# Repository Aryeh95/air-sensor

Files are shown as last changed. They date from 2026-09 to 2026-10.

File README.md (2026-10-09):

# Smart E-Ink Air Quality Monitor
This repository contains the ESPHome software configurations and 3D printed parts to build the Desktop Air Quality Monitor featured on [the channel](https://www.youtube.com/@FeatureNAB). 

> **This fork** builds the full variant **without a custom PCB**: it uses the off-the-shelf [Seeed Studio XIAO ePaper Display Board EE05](https://wiki.seeedstudio.com/epaper_ee05/) (XIAO ESP32-S3 Plus + e-paper driver) and a **Good Display GDEY0426T82** 4.26" 800x480 e-paper panel instead of the custom driver PCB and the 2.13" panel.

Watch the video (https://www.youtube.com/watch?v=DqiMmY5ppnE)

The device uses an ESP32 and the Sensirion SEN66 to track 9 different air quality metrics (PM1, PM2.5, PM4, PM10, VOCs, NOx, CO2, Temperature, and Humidity), plus formaldehyde with an optional Sensirion SFA40, and displays them on an e-ink screen. It connects natively to [Home Assistant](https://www.home-assistant.io/) and the firmware is written using [ESPHome](https://esphome.io/).

The original (2.13" + custom PCB) 3D files can be found on [Printables](https://www.printables.com/model/1751003-smart-desktop-air-quality-monitor-esp32-sen66), on [Makerworld](https://makerworld.com/en/models/2918992-smart-desktop-air-quality-monitor-esp32-sen66), or in the releases tab.
  
## What's in this Repository?

**If you just want the final ready-to-go files, check the [Releases tab](../../releases) on the right!**

All source files are organized into their respective folders: 

*   📂 **`enclosure/ee05_sen66_pod/`** - A SEN66 side-pod that bolts onto an EE05 + 4.26" enclosure, and the script that generates it.
*   📂 **`firmware/`** - ESPHome `.yaml` configuration files, plus precompiled bin files that you can flash directly to your board (Minimal and Home Assistant versions available).

## Getting Started

This project comes in 2 flavours - the minimal "just get the sensor working" variant, and the full variant with an e-paper display and a 3D printed housing.

### Minimal variant 

#### 1. Hardware
To build this version, you will need:

*   [Sensirion SEN66](https://mou.sr/44c63Ji)
*   [Seeed XIAO ESP32-C6](https://www.youtube.com/redirect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) microcontroller
*   [A JST-GH to Dupont cable](https://www.tinytronics.nl/en/cables-and-connectors/cables-and-adapters/jst-compatible/jst-ghr-06v-s-to-dupont-female-compatible-cable-6p-15cm) to connect them

Assemble by connecting the 3V, GND, SDA and SCL pins as shown in the video.

#### 2. Firmware

**Method A: "As Fast As Possible" (No Coding Required)**
1. If you plan to use the device with Home Assistant, download `Firmware_minimal_with_Home_Assistant_bins.zip `, if you plan to use it standalone use `Firmware_minimal_air_sensor_bins.zip ` from the Releases tab on the right side of this page.
2. Plug your ESP32 (C3, C5, C6, or S3) into your computer via USB.
3. Using a Web Serial compatible browser (like Chrome or Edge), go to [web.esphome.io](https://web.esphome.io).
4. Click "Connect", select your board's COM port, and upload the `.bin` file that matches your specific ESP32 model.
5. Connect to the device's fallback Wi-Fi network to add it to your home network!

**Method B: Do this if you already have Home Assistant (or want to customise your setup)**
1. Open the `Software` folder and grab the relevant `.yaml` config file. Copy its contents.
2. Paste it into your ESPHome Builder dashboard.
3. Edit your Wi-Fi credentials, encryption keys, and anything else you want to try.
4. "Install" to compile and flash directly to your board.

---

### Full Variant (EE05 + 4.26" e-paper, no custom PCB)

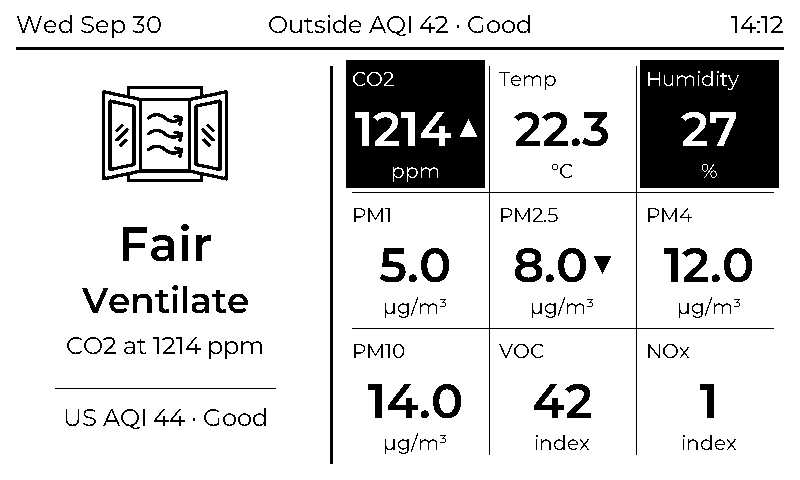
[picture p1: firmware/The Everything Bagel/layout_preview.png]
Display layout preview

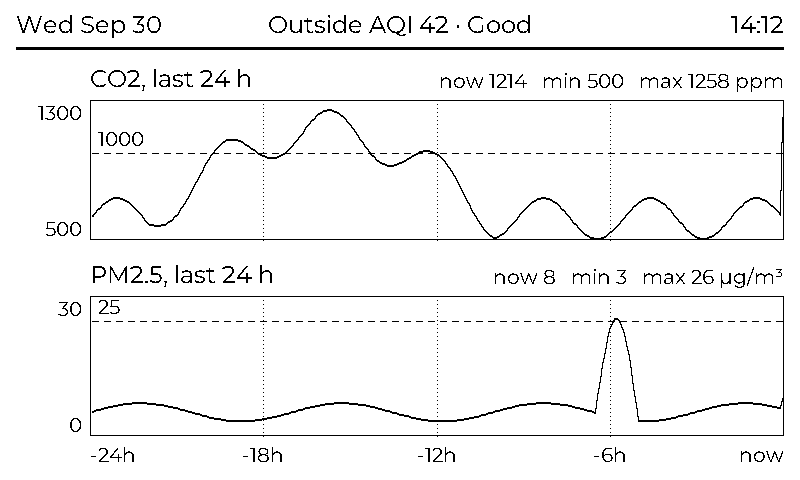
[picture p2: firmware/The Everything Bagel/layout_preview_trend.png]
Trend page preview

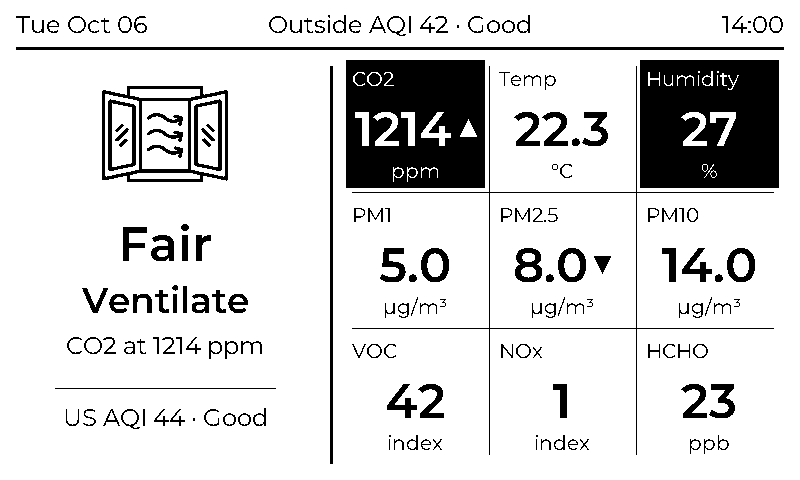
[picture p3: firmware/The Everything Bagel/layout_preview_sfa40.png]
With the optional SFA40 formaldehyde sensor


#### 1. Parts

| Part | Notes |
| --- | --- |
| [Sensirion SEN66](https://sensirion.com/products/catalog/SEN66) | The air quality sensor |
| JST GH 1.25 mm 6-pin cable, single-ended (plug on one end, bare wires on the other), 10–15 cm | SEN66 to EE05. Some SEN66 sellers include one |
| [Seeed Studio XIAO ePaper Display Board EE05](https://wiki.seeedstudio.com/epaper_ee05/) | XIAO ESP32-S3 Plus and 24-pin e-paper driver on one board. Replaces the custom PCB **and** the separate XIAO |
| [Good Display GDEY0426T82](https://buyepaper.com/products/gdey0426t82) | 4.26" 800x480 black/white e-paper (SSD1677), 24-pin FPC. Plugs straight into the EE05 |
| USB-C cable + 5 V supply | The SEN66's fan runs continuously, so run it from USB rather than a battery |
| EE05 + 4.26" enclosure (e.g. the "Cattt Casing") + the [SEN66 side-pod](enclosure/ee05_sen66_pod/) | Optional. Hardware: with heat-set inserts, 4× M3 + 4× M2 inserts and M3/M2 screws; without, the designer's M2.5 button-head screws. Details in the pod README |
| *Only if needed:* 2x 10 kΩ resistors and a little heat-shrink | I²C pull-ups, if the sensor doesn't work reliably on the ESP32's internal pull-ups (see step 3 below) |
| *Optional:* [Sensirion SFA40](https://sensirion.com/products/catalog/SFA40) formaldehyde sensor on a small breakout (about 17.5 × 15 mm; get the version without header pins), plus 26–28 AWG stranded wire | Adds formaldehyde (HCHO). Shares the SEN66's I²C wires. See "Optional: formaldehyde" below |

#### 2. Wiring

1. **Display.** Flip up the latch on the EE05's 24-pin connector, slide the GDEY0426T82's ribbon in straight with its gold contacts facing up (away from the board; Seeed's schematic lists it as a top-contact connector), and close the latch.
2. **Find pin 1 on the sensor cable.** Plug the cable into the SEN66. With the connector side facing you and the round fan housing on your right, pin 1 is at the left end. Wire colours aren't standardised, so go by position.
3. **Wires 5 and 6** are tied inside the sensor to GND and VDD. Cut them short and cover the ends with heat-shrink.
4. **Solder the other four into the EE05's pads.** Strip about 3 mm of each wire and solder it into its hole. The pads are the two rows of holes along the long edges beside the XIAO, labelled on the back of the board. If you're using the side-pod, feed the wires through the back plate's slot first.

| SEN66 pin | Signal | EE05 pad |
| --- | --- | --- |
| 1 | VDD | **3V3** |
| 2 | GND | **GND** |
| 3 | SDA | **D4** (GPIO5) |
| 4 | SCL | **D5** (GPIO6) |
| 5, 6 | GND / VDD | not connected, insulated |

*   **Don't use the 5V pad** next to GND. The SEN66 is a 3.3 V part (3.6 V absolute maximum).
*   **3V3 only has power while the firmware is running.** The EE05 switches the e-paper and the 3V3 pad with D6 / GPIO43, and the firmware turns it on at boot, so don't use D6 for anything else.
*   **Other pins in use:** the e-paper uses D3 (BUSY), D7 (CS), D8 (SCK), D10 (MOSI), D11 (RST) and D16 (DC). Key1 to Key3 are on D1, D2 and D9, and D0/D12 handle battery sensing. Check the pad names against the silkscreen and the [EE05 schematic](https://files.seeedstudio.com/wiki/Epaper/EE05/XIAO_ePaper_Display_Board_Ex05_V1.0.pdf) before soldering.

#### 3. Test, and add pull-ups only if needed

Sensirion's datasheet asks for 10 kΩ pull-up resistors on SDA and SCL. This build starts without them and relies on the ESP32's weak internal pull-ups, which usually work with a short cable at 100 kHz. (The original project's minimal variant runs the same way.)

Flash the firmware and watch the logs for a few minutes. If you see `Found i2c device at address 0x6B` and readings arrive every 30 s with no I²C or `sen6x` errors, you're done. If the sensor isn't found, or readings drop out, add two 10 kΩ pull-up resistors, spliced into the cable: one from wire 3 (SDA) to wire 1 (VDD), one from wire 4 (SCL) to wire 1. Slide heat-shrink on first, then cut each wire, twist the ends together with the resistor leg, solder, and shrink.

**Optional: formaldehyde (SFA40).** Solder its four pads to the same EE05 pads as the SEN66: Vcc to **3V3**, Gnd to **GND**, SDA to **D4**, SCL to **D5** (go by the labels on your board; the order varies). The two sensors have different I²C addresses (SEN66 0x6B, SFA40 0x5D), so they share the wires without conflict. Most SFA40 breakouts have 10 kΩ pull-ups on board, which then serve the SEN66 too: with the power off, about 10 kΩ between SDA and Vcc means they're there. Keep flux and solvents away from the sensor's membrane (the patch on its metal can). The firmware finds it automatically; look for `0x5D` next to `0x6B` in the boot log. Its first reading arrives about 10 minutes after power-on.

#### 4. Enclosure

Any EE05 + 4.26" enclosure works as long as the SEN66's inlets and outlet can reach room air. For the "Cattt Casing" (EE05 frame / back plate / back cap / stand), print the [SEN66 side-pod](enclosure/ee05_sen66_pod/) and make one cable hole in the back plate. Details are in that folder's README.

#### 5. Firmware
The config is `firmware/The Everything Bagel/air_sensor_epaper_ee05.yaml`. It needs ESPHome 2026.9 or newer (for the `sfa40` component; tested with 2026.9.1). There are two ways to build it with ESPHome Builder or the ESPHome CLI:

*   **Straight from GitHub (no files to copy).** Make your device's config just this, and ESPHome downloads the firmware files itself. To pick up changes, click Install again; `refresh` sets how often it checks GitHub (`always` checks every time). Settings from the list below can go under `substitutions:` here.
    ```yaml
    substitutions:
      use_fahrenheit: "false"

    packages:
      air_sensor:
        url: https://github.com/aryeh95/air-sensor
        ref: main            # the branch to build from
        files: ["firmware/The Everything Bagel/air_sensor_epaper_ee05.yaml"]
        refresh: 1d
    ```
*   **From local copies.** Copy `air_sensor_epaper_ee05.yaml`, `aqi_algo.h`, `display_renderer.h`, `device_extras.h` and the three `.png` icons into your ESPHome config folder, and copy them again after each update.

**Secrets.** Either way, put these in your own `secrets.yaml` in the ESPHome config folder (`secrets.example.yaml` in the repo lists them with placeholders; don't commit real values): `wifi_ssid`, `wifi_password`, `api_encryption_key` (also used for wireless updates), `fallback_ap_password`, `purpleair_api_key`, `purpleair_sensor_index`, `purpleair_backup_sensor_index` (optional), `airnow_api_key` and `airnow_zip`.

**Settings** at the top of the config (`substitutions:`):
*   `use_fahrenheit`: show °F on the display. Home Assistant still gets °C and converts it itself.
*   `temperature_offset`: if the case makes the sensor read warm, e.g. `"-1.5"`. Humidity is recalculated to match, so it stays correct.
*   `timezone`: for the clock.

**Standalone or with Home Assistant.** The device doesn't need Home Assistant. The clock uses internet time (SNTP), outdoor air quality comes straight from PurpleAir or AirNow, and the automatic reboot ESPHome normally does after 15 minutes without a Home Assistant connection is turned off. If Home Assistant is connected, it gets every reading, the advice text, and indoor and outdoor AQI sensors.

**Outdoor air quality.** The device uses outdoor PM2.5 to decide whether airing out is a good idea, and shows the outdoor AQI in the header. It has two sources:
*   **PurpleAir** (first choice): a nearby outdoor community sensor, fetched every 10 minutes and adjusted with the US EPA correction for PurpleAir sensors. Readings are skipped if the sensor is indoor, hasn't reported for 30 minutes, or its two laser counters disagree. You need a read API key from [develop.purpleair.com](https://develop.purpleair.com/) and the sensor's number, which is the `select=` value in its link on the PurpleAir map. You can also set a backup sensor, which is only asked when the main one has no usable reading, so it costs nothing extra on normal days. PurpleAir charges per request from a points balance: about 10 points per request, so roughly 43,000 a month. New accounts get 1,000,000 free points. Sensors that don't report humidity are corrected assuming 50%.
*   **AirNow** (fallback, US only): used when PurpleAir has no recent reading. Free API key from [docs.airnowapi.org](https://docs.airnowapi.org/), plus your ZIP code. Fetched every 30 minutes.

Either or both can be left unset; without any outdoor data that part is simply skipped. Home Assistant gets the outdoor AQI and PM2.5 in use, and which source they came from.

**The screen**
*   The main page shows the recommendation, icon and indoor US AQI on the left, and 9 readings on the right. With an SFA40 fitted, formaldehyde (HCHO, in ppb) takes the place of PM4, which Home Assistant still gets.
*   Readings past their limit are drawn white-on-black. The limits are CO2 over 1000 ppm, PM2.5 over 25, PM10 over 45, VOC index 150+, NOx index 20+, formaldehyde over 80 ppb and humidity outside 30–60%. They're all in `aqi_limits` in `aqi_algo.h`.
*   Formaldehyde over 80 ppb (the WHO guideline, 0.1 mg/m³) means "Ventilate", and over 40 ppb (Health Canada's long-term limit) "Cons. Vent". If the outside air is polluted, high formaldehyde still gets "Vent Briefly", because a purifier's particle filter doesn't remove it.
*   Arrows on CO2 and PM2.5 show a clear rise or fall over the last 10 minutes.
*   The header shows the date, outdoor AQI and time, plus a Wi-Fi-off icon when the connection drops.
*   If the SEN66 stops responding, the screen says so and shows dashes instead of old readings.
*   The screen only redraws when something visible changes, with a partial refresh. It does a full refresh every 30 redraws to clear ghosting.

**Keys on the side of the EE05**
*   **Key1**: redraw now.
*   **Key2**: switch to the 24-hour CO2 and PM2.5 trend page. It returns to the main page after 2 minutes. The history is kept in memory, so it starts again after a reboot.
*   **Key3**: full refresh, to clear ghosting.

If the image comes out mirrored or upside down on your panel, change `rotation:` (0/90/180/270), or add `transform: {mirror_x: false, mirror_y: false}` to the display.

**Desktop preview.** `esphome run eg_host.yaml` shows the screens with made-up readings (needs SDL2). Add `-s preview_page 1` for the trend page, `-s use_fahrenheit true -s preview_wifi false`, or `-s preview_hcho 23` for the layout with an SFA40.

## Home Assistant Dashboard

If you are connecting this to Home Assistant and want the UI dashboard card shown in the video, you will need to install HACS (Home Assistant Community Store) and download the **[Air Quality Card by KadenThomp36](https://github.com/KadenThomp36/air-quality-card)**. The thresholds and algorithms in my `aqi_algo.h` match the WHO 2021 recommendations also used by this card, so the recommendations shown on the physical display on this Air Quality device should match those on this card/dashboard.

## Support the project
[Patreon](https://www.patreon.com/FEATURE418) for anyone interested, so I can continue making projects like this. Thanks!

Some of the links on this page are affiliate links and help support these projects at no cost to you.

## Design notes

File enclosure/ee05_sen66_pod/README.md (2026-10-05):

# SEN66 side-pod for the EE05 + 4.26" enclosure

An add-on housing that mounts a Sensirion SEN66 on the back of the EE05 / 4.26" e-paper
enclosure (the "Cattt Casing": EN05 frame, support, back plate, back cap, stand, switch cap).
None of the original parts need reprinting. You only need one cable hole in the back plate.

- **`sen66_pod.stl`**: ready to print, already in print orientation.
- **`make_pod.py`**: generates the pod, and optionally modified copies of the original back plate (cable hole, M3 clearance holes), frame (M3 insert holes) and display support (M2 insert holes).

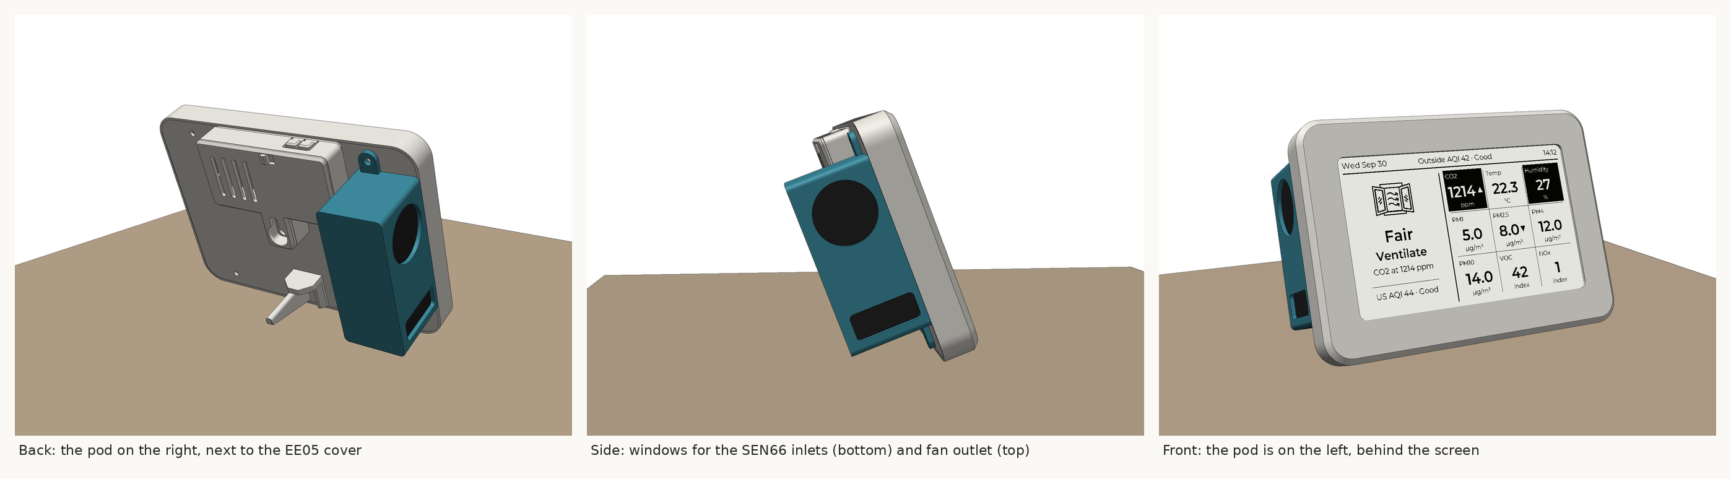
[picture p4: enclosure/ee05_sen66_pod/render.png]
The case with the pod attached: back, side and front


## How it fits

- The pod sits on the back plate beside the EE05 pocket, on the **right when you look at the back**
  of the case (the left when you look at the screen). It is held on by the **two existing
  back-plate screws on that side**, which pass through tabs on the pod.
- The SEN66 lies on its side with its inlets and outlet facing sideways through two windows in the
  pod's outer wall: inlets at the bottom, fan outlet at the top. Sensirion's guidelines allow
  sideways-facing openings, the solid wall between the windows keeps inlet and outlet air apart, and
  most of the sensor sits below the EE05 (the ESP32 is the main heat source).
- The sensor cable leaves through the channel under the sensor and goes into the case through one
  hole in the back plate.
- Checked against the original STLs: no overlap with any part, and about 2 mm of clearance from
  the desk when the case leans back on its stand (about 20°).

## Hardware

These sizes come from the designer's STEP assembly (EE05_4_26.step, on Seeed's GrabCAD), the STLs
and the EE05's PCB file. The designer's model uses four M2.5 button-head screws (McMaster 92095A113)
for the case, going through the back plate into the frame's bosses, and doesn't show any screws for
the EE05. There are two ways to build it.

**With heat-set inserts (recommended; the threads survive repeated opening).** Print the frame and
display support that `make_pod.py --frame ... --support ...` generates. They have holes sized to
CNC Kitchen's guidelines.

| Qty | Part | Goes |
| --- | --- | --- |
| 4 | **M3 × 5.7 heat-set insert** (hole 4.0 × 6.7 mm) | Into the frame's four screw bosses, from the back |
| 4 | **M2 × 3 heat-set insert** (hole 3.2 × 4.5 mm) | Into the display support's four EE05 posts |
| 2 | **M3 × 8 mm** machine screw, pan or button head | Back plate to frame: the two screws on the left, seen from the back |
| 2 | **M3 × 10 mm** machine screw, pan or button head | Through the pod's tabs and the back plate into the frame |
| 4 | **M2 × 5 mm** machine screw (M2 × 4 to M2 × 6 all fit) | EE05 board onto its posts |

- Press each insert in straight with a soldering iron at your usual insert temperature for the
  filament, until it's flush with, or just below, the top of the boss.
- The walls around the inserts are 1.9 mm for M3 and 1.5 mm for M2, above CNC Kitchen's minimums
  of 1.6 mm and 1.3 mm.
- The original hole continues below each insert hole, so the screw tips have room.
- **If your holes print undersize** (common with FDM), measure one and regenerate with the
  difference, e.g. `--hole-comp 0.5` when a 4.0 mm hole measures 3.5 mm. It enlarges every screw
  and insert hole (frame, support, back plate and pod tabs). With 0.5 the walls are still 1.6 mm
  (M3) and 1.4 mm (M2). Alternatively, use your slicer's hole compensation setting (not both).

**Without inserts, using the original frame and support (as the designer intended).** M2.5 screws
cut their own thread in the 2.5 mm printed bosses; printed holes come out slightly undersize.
Screws made for plastic ("PT" or thread-forming) grip best:

| Qty | Screw | Goes |
| --- | --- | --- |
| 2 | **M2.5 × 6 mm** button head | Back plate to frame: the two on the left, seen from the back |
| 2 | **M2.5 × 8 mm** button head | Through the pod's tabs |
| 4 | **M2 × 6 mm** | EE05 board onto the display support (2.0 mm pilot holes, 10 mm deep) |

The designer's model shows M2.5 × ~3 mm screws, which only reach about 1 mm into the bosses. The
lengths above give 4 mm of thread.

**Either way:**
- The frame's bosses are 8 mm across with 2.5 mm holes, 8.2 mm deep. The EE05's mounting holes are
  2.5 mm (M2 clearance), 27 × 21 mm apart, and line up with the display support's posts.
- The back plate generated here has 3.2 mm screw holes, for M3 through the inserts. M2.5 button
  heads also clamp fine through them. If you print the original back plate with M3 screws, drill
  its four holes out to 3.2 mm (a 1/8" bit is fine).
- The back cap, stand and switch cap have no screw holes.
- **EE05 orientation:** in the designer's model the board sits on the four posts with its components
  facing the back cover. Its labelled side, with the pad names, faces the display, so solder the
  sensor wires before screwing the board in.
- **Battery (optional):** the design has room for a 62.5 × 40.5 × 7 mm LiPo behind the lower half of
  the display. The pod's cable hole is clear of it by about 5 mm. The SEN66's fan runs all the
  time, so plan on USB power anyway.

## Printing

- Print `sen66_pod.stl` as is (tabs flat on the bed). No supports: the back wall bridges 22 mm.
- 0.2 mm layers, 3 walls, PLA or PETG.

## Assembly

1. **Cable hole.** Either
   - drill a ~9 mm hole in the back plate. Looking at the outside of the back plate (from behind
     the case), it's centred on the line between the two right-hand screw holes, ~1 mm below
     halfway between them: 17.5 mm in from the right-hand edge and 43 mm down from the top edge.
     Or
   - generate a back plate with the hole (and 3.2 mm screw holes) already in it:
     `python make_pod.py --backplate "Backplate.stl"`
2. Feed the bare-wire end of the SEN66 cable through the hole from the outside and plug the
   connector into the sensor. Route the cable through the channel under the sensor.
3. Put the SEN66 into the pod with its inlet/outlet face against the windows (round fan outlet in
   the top window) and the connector side against the inner wall.
4. Put the pod, with the sensor in it, onto the back plate and fix it with the two screws on that
   side (the right, seen from the back): **M3 × 10**, 2 mm longer than the others because of the
   2 mm tabs.
5. Seal the hole around the cable from the inside with a bit of Blu-Tack, so the SEN66 can't draw
   air from inside the case.
6. Optional: a strip of thin foam tape on the sensor face between the inlets and the outlet
   improves the seal against the pod wall.

## Regenerating / tweaking

```
pip install trimesh manifold3d numpy
python make_pod.py [--backplate Backplate.stl] [--frame "EN05 frame thick.stl"] [--support support.stl] [--hole-comp 0.5] [--assembly]
```

All dimensions (wall thickness, clearance, tab size, screw hole size, pod position) are
constants at the top of `make_pod.py`. `--assembly` also writes the pod in the enclosure's
assembly coordinates, so you can load it together with the original STLs to check the fit.

This pod is designed from measurements of the enclosure STLs and the SEN66 datasheet. It hasn't
been test-printed yet, so print it and dry-fit it before final assembly.

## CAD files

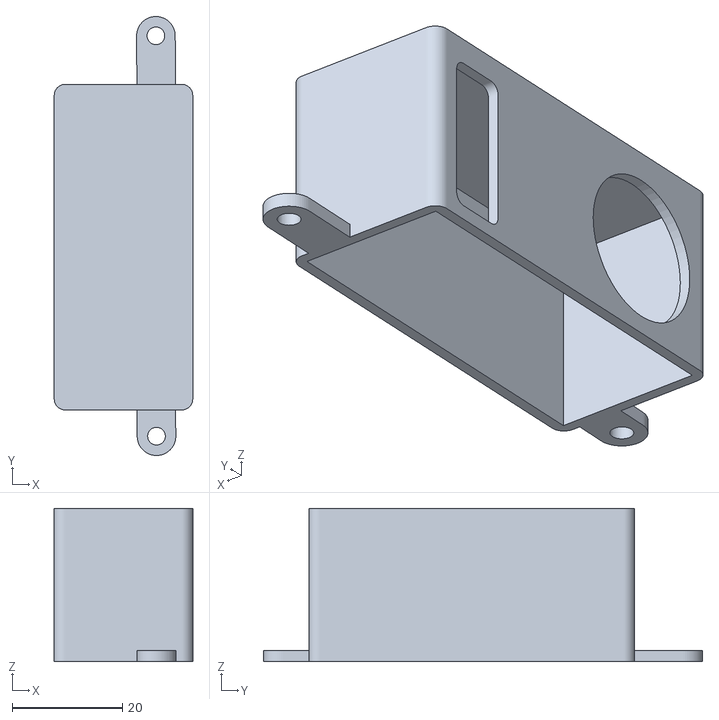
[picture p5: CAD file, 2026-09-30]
enclosure/ee05_sen66_pod/sen66_pod.stl
25.1 x 79.5 x 27.8

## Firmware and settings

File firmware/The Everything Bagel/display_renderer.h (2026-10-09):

#pragma once
#include "esphome.h"
#include "aqi_algo.h"

// Screens for the GDEY0426T82 4.26" panel: 800x480, landscape.
//
// Main page                                            Trend page (Key2)
// +--------------------------------------------------+ +--------------------------------------+
// | Date          Outside AQI 42 · Good         Time | | Date          Outside AQI ...   Time |
// +---------------+----------------------------------+ +--------------------------------------+
// |               |  CO2 ↑     |  Temp     | Humidity | | CO2, last 24 h                       |
// |    [icon]     |------------+-----------+----------| |  ~~~~~~~~~~~~~~~~~~~~~~~~~~~~~~~~~~  |
// |    Status     |  PM1       |  PM2.5 ↓  | PM4      | | PM2.5, last 24 h                     |
// |    Action     |------------+-----------+----------| |  ~~~~~~~~~~~~~~~~~~~~~~~~~~~~~~~~~~  |
// |    Reason     |  PM10      |  VOC      | NOx      | |  -24h   -18h   -12h   -6h      now   |
// |  US AQI 23    |   (tiles past a limit are inverted)| +--------------------------------------+
// +---------------+----------------------------------+
//
// With an SFA40 formaldehyde sensor fitted, the bottom two rows become
// PM1 | PM2.5 | PM10  and  VOC | NOx | HCHO  (PM4 stays available in Home Assistant).
//
// The fonts used below (montserrat_20/24/36/48) are the ids from the YAML; ESPHome declares
// them in main.cpp before this header is included.

namespace layout {
static const int WIDTH = 800;
static const int HEIGHT = 480;
static const int MARGIN = 16;
static const int HEADER_HEIGHT = 50;
static const int HEADER_TEXT_Y = (HEADER_HEIGHT - 4) / 2;

// Left panel: recommendation
static const int LEFT_WIDTH = 330;
static const int LEFT_CENTER = LEFT_WIDTH / 2;

// Right panel: 3x3 grid of readings
static const int GRID_X = LEFT_WIDTH + 12;
static const int GRID_Y = HEADER_HEIGHT + 6;
static const int GRID_COLS = 3;
static const int GRID_ROWS = 3;
static const int TILE_WIDTH = (WIDTH - MARGIN - GRID_X) / GRID_COLS;
static const int TILE_HEIGHT = (HEIGHT - MARGIN - GRID_Y) / GRID_ROWS;
static const int TILE_PADDING = 10;
}  // namespace layout

static const Color PAPER = Color::WHITE;
static const Color INK = Color::BLACK;

enum class Trend { DOWN = -1, FLAT = 0, UP = 1 };

// ---------------------------------------------------------------------------
// Reading history: 24 h of 5-minute averages for the trend page, plus the last
// ~24 min of raw readings for the trend arrows. Kept in RAM, so it restarts on reboot.
// ---------------------------------------------------------------------------
class ReadingHistory {
 public:
  static constexpr uint32_t BUCKET_MS = 5UL * 60UL * 1000UL;
  static constexpr int SLOTS = 288;  // 24 h
  static constexpr int RECENT = 48;  // raw readings, one every 30 s
  static constexpr uint32_t TREND_MS = 10UL * 60UL * 1000UL;

  void add(uint32_t now, float co2, float pm25) {
    recent_[recent_head_] = {now, co2, pm25};
    recent_head_ = (recent_head_ + 1) % RECENT;
    if (recent_count_ < RECENT)
      recent_count_++;

    uint32_t bucket = now / BUCKET_MS;
    if (!bucket_open_) {
      open_bucket_(bucket);
    } else if (bucket != bucket_id_) {
      close_bucket_();
      uint32_t gap = bucket - bucket_id_ - 1;  // buckets with no readings at all
      if (gap > (uint32_t) SLOTS)
        gap = 0;  // millis() wrapped (every ~49 days): treat as contiguous
      for (uint32_t i = 0; i < gap; i++)
        push_(NAN, NAN);
      open_bucket_(bucket);
    }
    if (!std::isnan(co2)) {
      co2_sum_ += co2;
      co2_n_++;
    }
    if (!std::isnan(pm25)) {
      pm_sum_ += pm25;
      pm_n_++;
    }
  }

  // Changes once per finished 5-minute bucket
  uint32_t version() const { return version_; }

  // Number of points for the graph, newest first (point 0 is the current, unfinished bucket)
  int points() const { return size_ + (bucket_open_ ? 1 : 0); }
  void point(int age, float &co2, float &pm25) const {
    if (bucket_open_) {
      if (age == 0) {
        co2 = co2_n_ ? co2_sum_ / co2_n_ : NAN;
        pm25 = pm_n_ ? pm_sum_ / pm_n_ : NAN;
        return;
      }
      age--;
    }
    int idx = (head_ + SLOTS - 1 - age) % SLOTS;
    co2 = co2_[idx];
    pm25 = pm_[idx];
  }

  // Compares the latest reading with the newest one at least 10 minutes older
  Trend trend(bool for_co2) const {
    if (preview_) return for_co2 ? preview_co2_ : preview_pm_;
    if (recent_count_ < 2)
      return Trend::FLAT;
    const Sample &latest = recent_[(recent_head_ + RECENT - 1) % RECENT];
    for (int i = 1; i < recent_count_; i++) {
      const Sample &old = recent_[(recent_head_ + RECENT - 1 - i) % RECENT];
      if (latest.ms - old.ms < TREND_MS)
        continue;
      float a = for_co2 ? old.co2 : old.pm25;
      float b = for_co2 ? latest.co2 : latest.pm25;
      if (std::isnan(a) || std::isnan(b))
        return Trend::FLAT;
      float threshold = for_co2 ? 50.0f : std::max(2.0f, a * 0.25f);
      if (b - a >= threshold)
        return Trend::UP;
      if (a - b >= threshold)
        return Trend::DOWN;
      return Trend::FLAT;
    }
    return Trend::FLAT;
  }

  // For the desktop preview only
  void push_bucket_for_preview(float co2, float pm25) {
    push_(co2, pm25);
  }
  void set_trends_for_preview(Trend co2, Trend pm25) {
    preview_ = true;
    preview_co2_ = co2;
    preview_pm_ = pm25;
  }

 private:
  struct Sample {
    uint32_t ms;
    float co2, pm25;
  };
  void open_bucket_(uint32_t id) {
    bucket_open_ = true;
    bucket_id_ = id;
    co2_sum_ = pm_sum_ = 0;
    co2_n_ = pm_n_ = 0;
  }
  void close_bucket_() {
    push_(co2_n_ ? co2_sum_ / co2_n_ : NAN, pm_n_ ? pm_sum_ / pm_n_ : NAN);
  }
  void push_(float co2, float pm25) {
    co2_[head_] = co2;
    pm_[head_] = pm25;
    head_ = (head_ + 1) % SLOTS;
    if (size_ < SLOTS)
      size_++;
    version_++;
  }

  float co2_[SLOTS]{};
  float pm_[SLOTS]{};
  int head_ = 0, size_ = 0;
  uint32_t version_ = 0;
  bool bucket_open_ = false;
  uint32_t bucket_id_ = 0;
  float co2_sum_ = 0, pm_sum_ = 0;
  int co2_n_ = 0, pm_n_ = 0;
  Sample recent_[RECENT]{};
  int recent_head_ = 0, recent_count_ = 0;
  bool preview_ = false;
  Trend preview_co2_ = Trend::FLAT, preview_pm_ = Trend::FLAT;
};

// ---------------------------------------------------------------------------
// What's on screen. The display only redraws when this changes.
// ---------------------------------------------------------------------------
struct Tile {
  const char *label = "";
  std::string unit;
  std::string value;
  bool alert = false;
  Trend trend = Trend::FLAT;
};
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

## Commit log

2026-09-30 Build without custom PCB: Seeed EE05 + GDEY0426T82 4.26" e-paper
    - Replace the custom e-paper driver PCB and XIAO ESP32-C6 with the Seeed
    XIAO ePaper Display Board EE05 (XIAO ESP32-S3 Plus + 24-pin driver).
    - Drive the Good Display GDEY0426T82 (800x480, SSD1677) via ESPHome's
    epaper_spi platform; switch on the EE05's e-paper/VCC_3V3 load switch
    (GPIO43) at boot; SEN66 on D4/D5; Key1 forces a redraw.
    - New single-screen 800x480 landscape layout (recommendation + 3x3 grid of
    all 9 readings), with black-on-white colours for the new driver.
    - Drop extern font declarations that conflict with current ESPHome codegen.
    - Update the SDL desktop preview config for the new layout.
    - Add a SEN66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
    [1096.step, CONN-SMD_4P-P1.00_SM04B-SRSS-TB-LF-SN.step, CONN-SMD_SM03B-SRSS-TB-LF-SN-P.step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]
2026-09-30 Wire the SEN66 directly first; pull-ups only if needed
    - README: default wiring is a single-ended GH 6-pin cable soldered straight
    to 3V3/GND/D4/D5, relying on the ESP32's internal pull-ups. New "test,
    and add pull-ups only if needed" step: if the sensor is flaky, splice two
    10k resistors into the cable.
    - Firmware: set sda/scl_pullup_enabled explicitly (already the ESP32
    default) with a comment pointing at the fallback.
    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
2026-09-30 Firmware: bug fixes, AirNow outdoor data, standalone mode, new UI features
    Bug fixes
    - Show "Offline"/"No Sensor" and dashes instead of stale readings when the
    SEN66 stops responding or is never found.
    - Outdoor override only holds back ventilation when outdoor PM2.5 is
    actually polluted (> 15 ug/m3 and worse than inside); urgent CO2 becomes
    "Vent Briefly" instead of "Keep Closed". Drop the outdoor CO2 comparison.
    - Icons follow the advice (enum instead of string matching): new icons for
    keep closed, too dry, too humid, starting and sensor fault.
    - Consistent "PM2.5 at N ug/m3" reasons.
    - Recalculate on CO2, the last value the SEN66 driver publishes, so the
    advice no longer uses th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
    [display_renderer.h]
2026-09-30 Outdoor air quality from a nearby PurpleAir sensor, AirNow as fallback
    - Fetch one outdoor PurpleAir sensor every 10 minutes and apply the US EPA
    correction for PurpleAir (Barkjohn 2021, extended for smoke). Skip the
    reading if the sensor is indoor, stale (>30 min) or its A/B channels
    disagree (EPA QA check).
    - PurpleAir is used while it's fresh (<45 min); otherwise AirNow (<3 h).
    The advice, header AQI and HA sensors follow whichever is in use; new
    "Outdoor Data Source" text sensor.
    - PurpleAir key and sensor number live in secrets.yaml; sensor "0" turns
    PurpleAir off.
    - Unit-tested the correction (continuity at breakpoints, clamping) and the
    parser (good, disagreeing, stale,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
    [display_renderer.h]
2026-09-30 PurpleAir: optional backup sensor; handle sensors without humidity
    - purpleair_backup_sensor_index (secret, "0" = none) is only queried when
    the main sensor has no usable reading (HTTP error, stale, indoor,
    channels disagree), so it costs no points on normal days. Order:
    main sensor, backup sensor, AirNow.
    - Sensors that don't report humidity (e.g. some PA-II-FLEX) were rejected;
    now the EPA correction assumes 50% RH (the RH term is ~0.9 ug/m3 per
    10%) and the log line says so.
    Claude-Session: https://claude.ai/code/session_01MBJcsLa3XsciJNA7uDyb8s
2026-09-30 Pod docs: fix which side the pod is on; add a render
    The pod is on the +X side of the enclosure, which is the right-hand side
    seen from the back (the left seen from the screen). The docs and script
    comments said "right as seen from the front". Fixed the pod README, the
    main README's screw note and the make_pod.py comments, and made the drill
    position explicit ("looking at the outside of the back plate"). Geometry
    is unchanged (pod STL regenerates byte-identical).
    Adds render.png: back, side and front views of the case with the pod,
    rendered from the actual STLs.
    Claude-Session: https://claude.ai/code/session_01MBJcsLa3XsciJNA7uDyb8s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
2026-09-30 Pod README: hardware list; back plate gets M3 clearance holes
    Measured from the STLs and the EE05 PCB file (the original design lists
    no hardware): the frame bosses are 2.5 mm x 8 mm (M3 tap drill), the EE05
    has 2.5 mm mounting holes matching the display support's 2.0 mm posts
    (M2). So: 2x M3x8, 2x M3x10 through the pod tabs, 4x M2x6 for the EE05.
    The original back plate's screw holes are 2.5 mm, too tight for M3 to
    pass through; make_pod.py --backplate now also opens them to 3.2 mm.
    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
2026-09-30 Heat-set insert option for the frame and display support
    make_pod.py --frame / --support write copies of the original parts with
    holes for CNC Kitchen inserts: M3 x 5.7 in the frame's four case-screw
    bosses (4.0 mm x 6.7 mm, 1.9 mm walls) and M2 x 3 in the display
    support's four EE05 posts (3.2 mm x 4.5 mm, 1.5 mm walls). The original
    holes continue below for screw-tip clearance. Verified watertight, hole
    profiles and wall thickness against CNC Kitchen's minimums.
    Pod README: hardware tables for building with and without inserts.
    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
2026-09-30 Pod README: hardware per the designer's STEP assembly
    The designer's assembly (EE05_4_26.step on Seeed's GrabCAD) shows four
    McMaster 92095A113 button-head screws: M2.5 (4.5 mm heads, ~2.4 mm
    shank), which is why the back plate and frame bosses both have 2.5 mm
    holes. The no-insert option now uses M2.5 (x6 / x8 through the pod tabs)
    instead of M3; the heat-set insert option (M3 inserts, M3 screws) is
    unchanged. Also notes the EE05's orientation (components towards the back
    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
2026-10-05 Pod generator: add --hole-comp to enlarge screw and insert holes for undersize printers
    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
2026-10-06 Optional SFA40 formaldehyde sensor; update config for ESPHome 2026.9
    - Auto-detected SFA40 on the shared I2C bus: an HCHO tile replaces PM4 and
    formaldehyde feeds the advice (80 ppb WHO guideline, 40 ppb watch level)
    - Readings older than 3 minutes are ignored
    - ESPHome 2026.9 syntax: image platforms, sen6x voc_index/nox_index, and OTA
    encryption using the API key instead of a separate OTA password
    - Preview: -s preview_hcho <ppb>
    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
    [display_renderer.h]
2026-10-09 AirNow: move to the replacement ziplatlong service; full refresh on big changes
    - AirNow retired /aq/observation/zipCode/current/ on 1 October 2026 (HTTP 410).
    Use /aq/observation/current/ziplatlong/, which returns nowcastAQI and
    parameterName; log AirNow's error message when there's no reading
    - Full e-paper refresh when the page or advice changes: a partial refresh
    leaves large new black areas grey and speckled. Full refresh every 20
    redraws instead of 30
    - get_raw_state() instead of the deprecated raw_state (removed in 2026.10)
    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
    [display_renderer.h]
2026-10-09 Retry redraws while the e-paper is still busy
    epaper_spi ignores update() until the previous frame is done ("Display
    already in state ..."), which dropped redraws when two refreshes came close
    together. Check the driver state first and retry 2 s later, keeping any owed
    full refresh. Key3 now requests the full refresh through the same path.
    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
2026-10-14 Pod: size the pocket for a measured SEN66; add --cavity-comp
    A real SEN66 measures 55.0 x 26.0 x 21.2 mm, 0.4 mm wider than the datasheet,
    which left only 0.1 mm per side. The pocket now uses the larger of the two.
    --cavity-comp adds clearance for printers that print inside features small.
    Re-checked: no overlap with the case parts, about 2 mm off the desk.
    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
2026-10-14 Pod README: cable leaves the groove on the SENSIRION-logo side
    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
2026-10-15 Pod: --sensor to size the pocket for a measured SEN66
    A test print with --cavity-comp 0.25 left about 1.2 mm of play: large pockets
    print close to size on the same printer that makes small holes 0.5 mm small.
    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
